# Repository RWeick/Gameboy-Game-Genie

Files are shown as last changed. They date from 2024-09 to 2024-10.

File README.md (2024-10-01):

# Gameboy-Game-Genie
The Kicad files and rom dump of the Gameboy Game Genie by Galoob. This includes the additional PCBs for the buttons and the LED.

In the replacement board folder, you will find a version of the PCB that uses an Atmel AT27C256 (or chip of compatible size and pinout) to replace the chip blob. This enables anyone with a damaged PCB to restore the system. It has been tested.

PCB Thicknesses: 0.8 mm

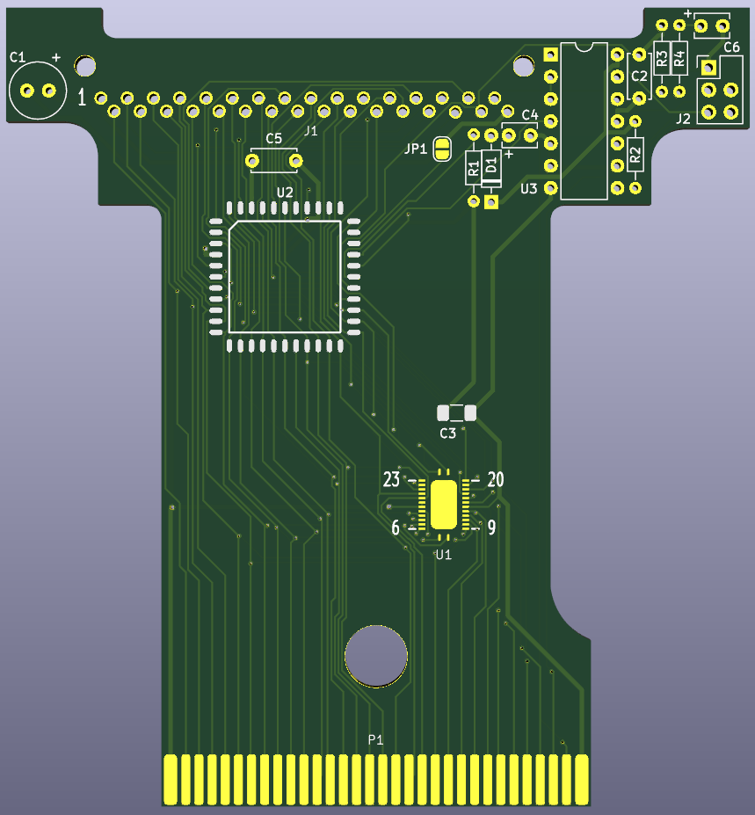
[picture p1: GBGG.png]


Replacement Board:

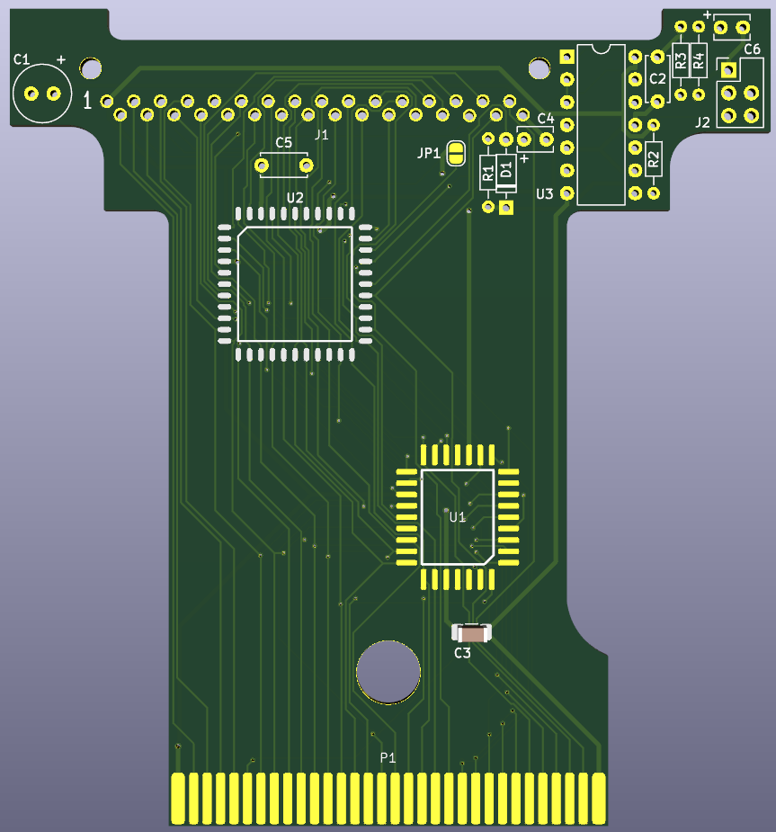
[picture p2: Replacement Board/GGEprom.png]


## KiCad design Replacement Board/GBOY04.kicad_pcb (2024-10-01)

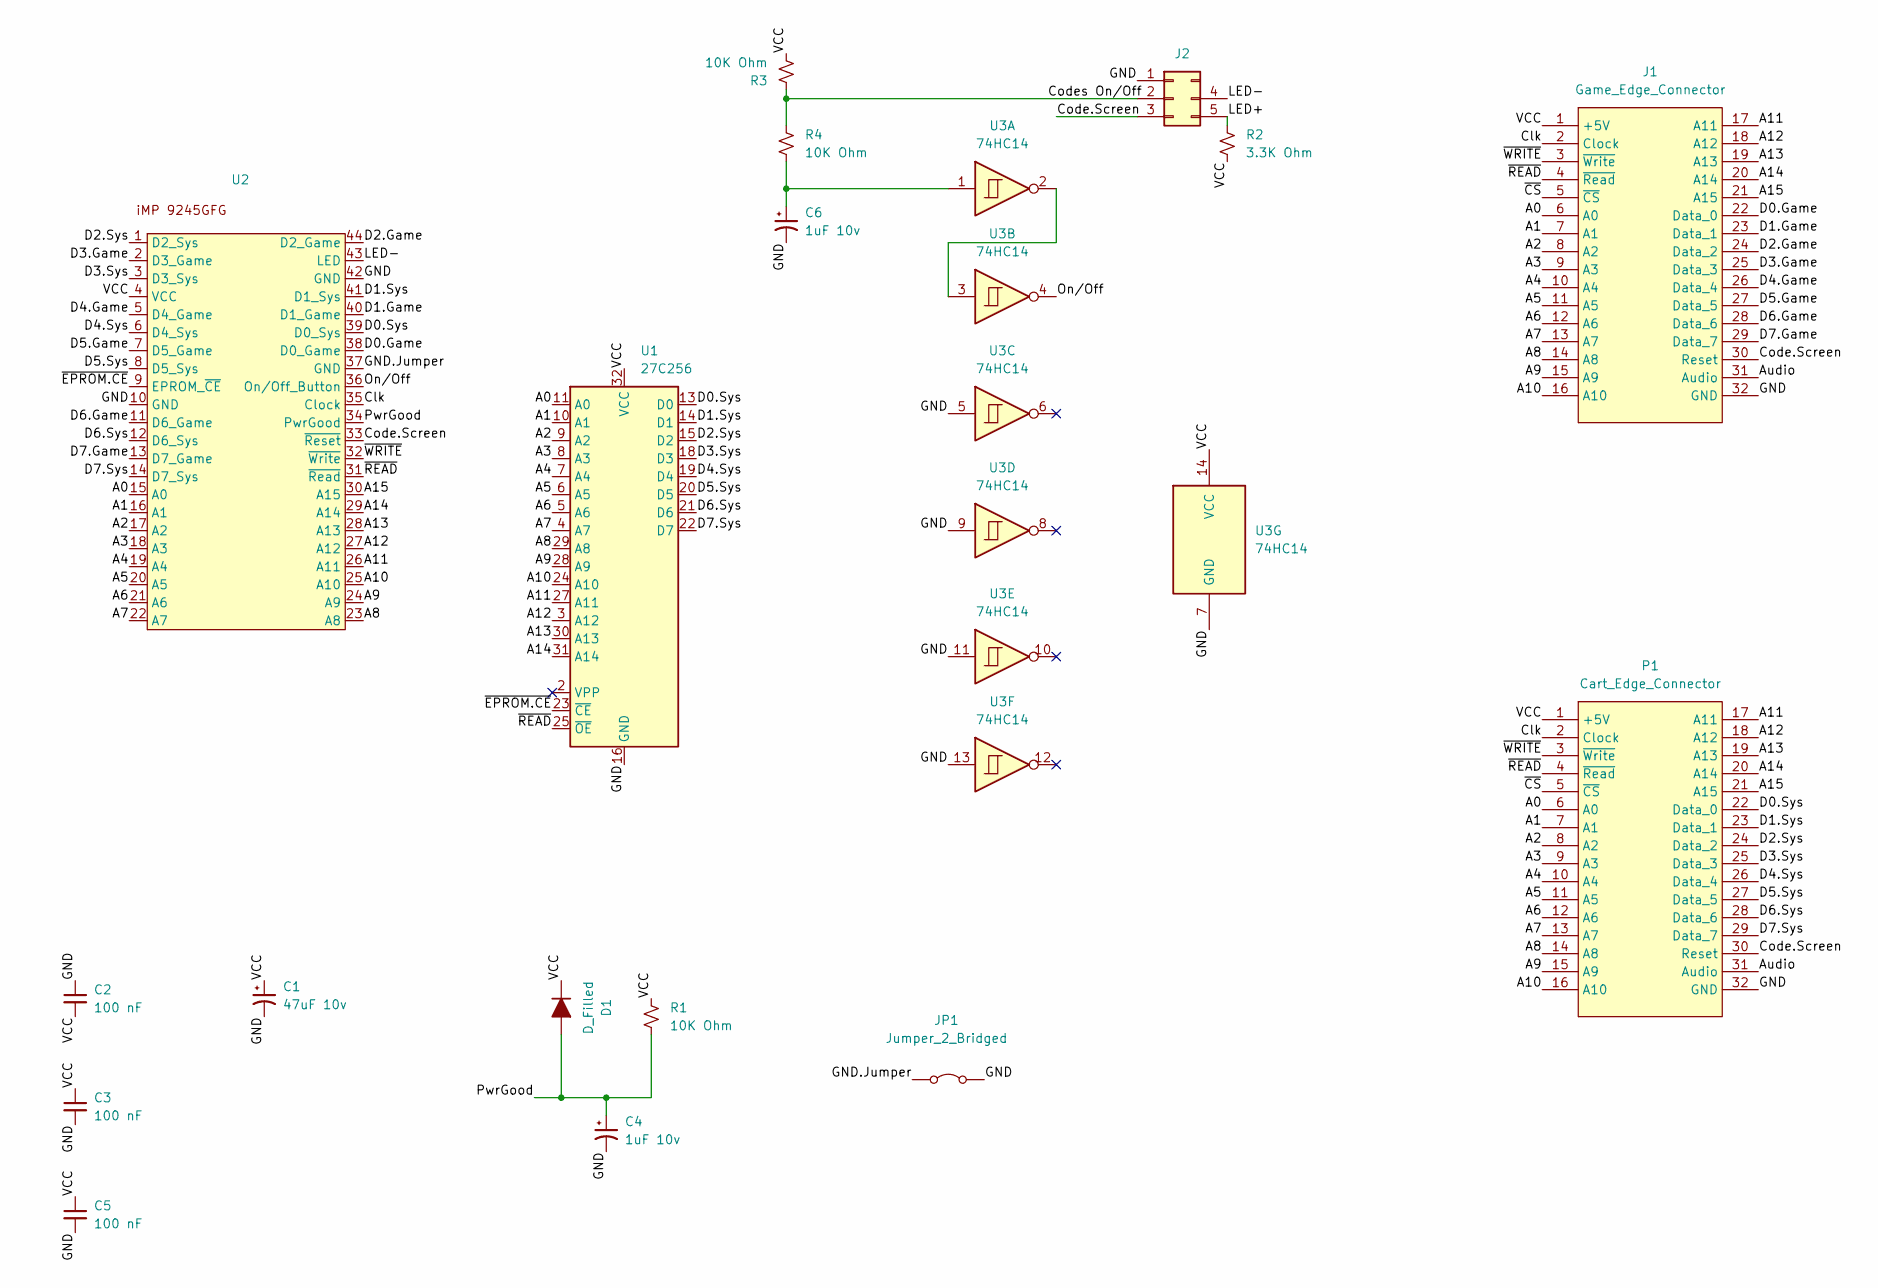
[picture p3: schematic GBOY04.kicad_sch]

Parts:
C1: 47uF 10v; C_Radial_D6.3mm_H5.0mm_P2.50mm
C2, C5: 100 nF; C_Disc_D5.0mm_W2.5mm_P5.00mm
C3: 100 nF; C_1206_3216Metric_Pad1.33x1.80mm_HandSolder
C4, C6: 1uF 10v; C_Disc_D3.8mm_W2.6mm_P2.50mm
D1: D_Filled; D_DO-35_SOD27_P7.62mm_Horizontal
J1: Game_Edge_Connector; Cartridge Connector
J2: Conn_02x03_Counter_Clockwise; PinHeader_2x03_P2.54mm_Vertical
JP1: Jumper_2_Bridged; SolderJumper-2_P1.3mm_Open_RoundedPad1.0x1.5mm
P1: Cart_Edge_Connector; Edge Connector
R1, R3, R4: 10K Ohm; R_Axial_DIN0204_L3.6mm_D1.6mm_P7.62mm_Horizontal
R2: 3.3K Ohm; R_Axial_DIN0204_L3.6mm_D1.6mm_P7.62mm_Horizontal
U1: 27C256; EPROM
U2: iMP PLD
U3: 74HC14; DIP-14_W7.62mm

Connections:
/A0: J1.6 (A0), P1.6 (A0), U1.11 (A0), U2.15 (A0)
/A1: J1.7 (A1), P1.7 (A1), U1.10 (A1), U2.16 (A1)
/A2: J1.8 (A2), P1.8 (A2), U1.9 (A2), U2.17 (A2)
/A3: J1.9 (A3), P1.9 (A3), U1.8 (A3), U2.18 (A3)
/A4: J1.10 (A4), P1.10 (A4), U1.7 (A4), U2.19 (A4)
/A5: J1.11 (A5), P1.11 (A5), U1.6 (A5), U2.20 (A5)
/A6: J1.12 (A6), P1.12 (A6), U1.5 (A6), U2.21 (A6)
/A7: J1.13 (A7), P1.13 (A7), U1.4 (A7), U2.22 (A7)
/A8: J1.14 (A8), P1.14 (A8), U1.29 (A8), U2.23 (A8)
/A9: J1.15 (A9), P1.15 (A9), U1.28 (A9), U2.24 (A9)
/A10: J1.16 (A10), P1.16 (A10), U1.24 (A10), U2.25 (A10)
/A11: J1.17 (A11), P1.17 (A11), U1.27 (A11), U2.26 (A11)
/A12: J1.18 (A12), P1.18 (A12), U1.3 (A12), U2.27 (A12)
/A13: J1.19 (A13), P1.19 (A13), U1.30 (A13), U2.28 (A13)
/A14: J1.20 (A14), P1.20 (A14), U1.31 (A14), U2.29 (A14)
/A15: J1.21 (A15), P1.21 (A15), U2.30 (A15)
/Audio: J1.31 (Audio), P1.31 (Audio)
/Clk: J1.2 (Clock), P1.2 (Clock), U2.35 (Clock)
/Code.Screen: J1.30 (Reset), J2.3, P1.30 (Reset), U2.33 (~Reset)
/Codes On/Off: J2.2, R3.1, R4.1
/D0.Game: J1.22 (Data_0), U2.38 (D0_Game)
/D0.Sys: P1.22 (Data_0), U1.13 (D0), U2.39 (D0_Sys)
/D1.Game: J1.23 (Data_1), U2.40 (D1_Game)
/D1.Sys: P1.23 (Data_1), U1.14 (D1), U2.41 (D1_Sys)
/D2.Game: J1.24 (Data_2), U2.44 (D2_Game)
/D2.Sys: P1.24 (Data_2), U1.15 (D2), U2.1 (D2_Sys)
/D3.Game: J1.25 (Data_3), U2.2 (D3_Game)
/D3.Sys: P1.25 (Data_3), U1.18 (D3), U2.3 (D3_Sys)
/D4.Game: J1.26 (Data_4), U2.5 (D4_Game)
/D4.Sys: P1.26 (Data_4), U1.19 (D4), U2.6 (D4_Sys)
/D5.Game: J1.27 (Data_5), U2.7 (D5_Game)
/D5.Sys: P1.27 (Data_5), U1.20 (D5), U2.8 (D5_Sys)
/D6.Game: J1.28 (Data_6), U2.11 (D6_Game)
/D6.Sys: P1.28 (Data_6), U1.21 (D6), U2.12 (D6_Sys)
/D7.Game: J1.29 (Data_7), U2.13 (D7_Game)
/D7.Sys: P1.29 (Data_7), U1.22 (D7), U2.14 (D7_Sys)
/GND: C1.2, C2.1, C3.2, C4.2, C5.2, C6.2, J1.32 (GND), J2.1, JP1.2 (B), P1.32 (GND), U1.16 (GND), U2.10 (GND), U2.42 (GND), U3.5, U3.7 (GND), U3.9, U3.11, U3.13
/GND.Jumper: JP1.1 (A), U2.37 (GND)
/LED+: J2.5, R2.1
/LED-: J2.4, U2.43 (LED)
/On/Off: U2.36 (On/Off_Button), U3.4
/PwrGood: C4.1, D1.2 (A), R1.2, U2.34 (PwrGood)
/VCC: C1.1, C2.2, C3.1, C5.1, D1.1 (K), J1.1 (+5V), P1.1 (+5V), R1.1, R2.2, R3.2, U1.32 (VCC), U2.4 (VCC), U3.14 (VCC)
/~CS: J1.5 (~CS), P1.5 (~CS)
/~EPROM.CE: U1.23 (~CE), U2.9 (EPROM_~CE)
/~READ: J1.4 (~Read), P1.4 (~Read), U1.25 (~OE), U2.31 (~Read)
/~WRITE: J1.3 (~Write), P1.3 (~Write), U2.32 (~Write)
unnamed: C6.1, R4.2, U3.1
unnamed: U3.2, U3.3

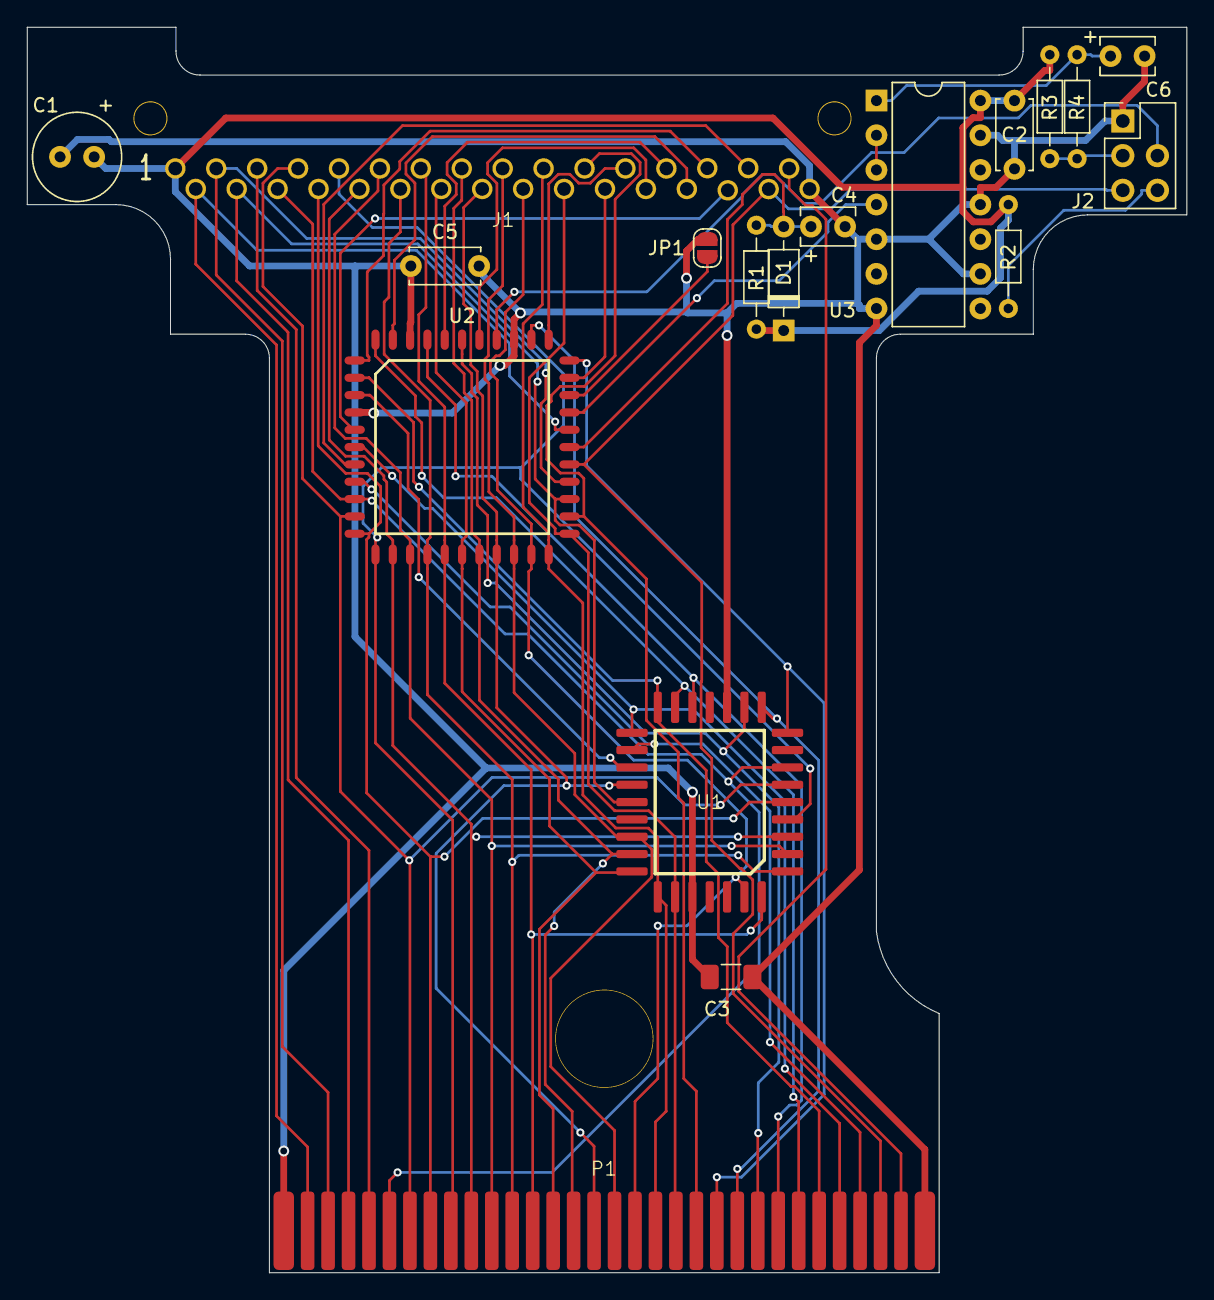
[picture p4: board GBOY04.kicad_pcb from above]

Board: 2 copper layers, 85.0 x 91.3 mm, 19 parts (0 on the bottom side), 49 nets.

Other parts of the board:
Hole: Drill Hole

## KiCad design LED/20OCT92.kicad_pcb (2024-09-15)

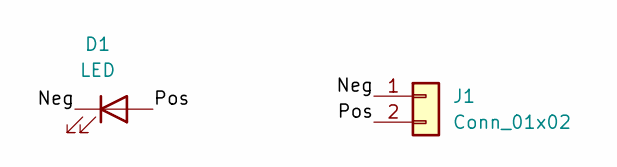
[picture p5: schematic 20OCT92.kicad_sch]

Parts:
D1: LED; LED_D4.0mm
J1: Conn_01x02; PinHeader_1x02_P2.54mm_Vertical

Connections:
/Neg: D1.1 (K), J1.1
/Pos: D1.2 (A), J1.2

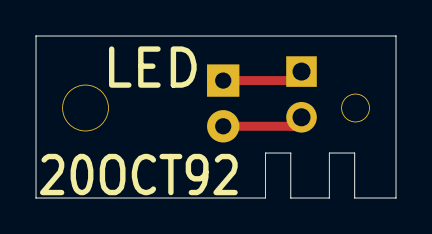
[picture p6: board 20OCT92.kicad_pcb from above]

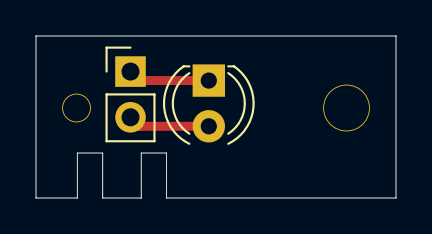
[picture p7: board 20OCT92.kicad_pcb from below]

Board: 2 copper layers, 20.0 x 9.0 mm, 3 parts (2 on the bottom side), 2 nets.

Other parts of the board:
Hole: Drill Holes

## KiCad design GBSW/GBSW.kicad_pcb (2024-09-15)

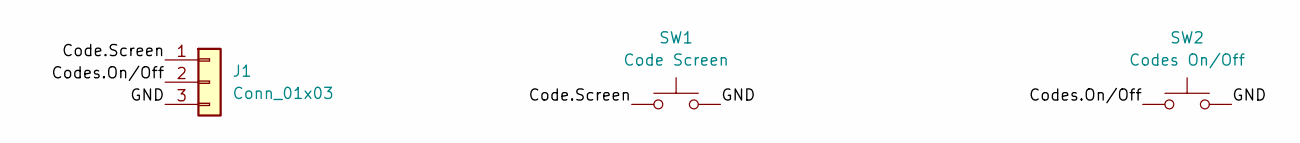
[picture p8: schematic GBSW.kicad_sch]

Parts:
J1: Conn_01x03; Wires
SW1: Code Screen; Buttons
SW2: Codes On/Off; Buttons

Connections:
/Code.Screen: J1.1, SW1.1
/Codes.On/Off: J1.2, SW2.1
/GND: J1.3, SW1.2, SW2.2

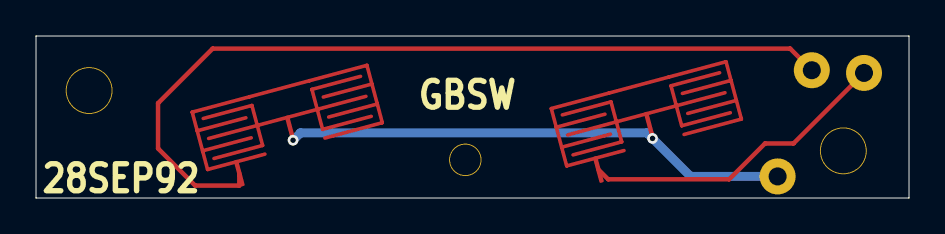
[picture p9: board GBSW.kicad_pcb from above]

Board: 2 copper layers, 48.5 x 9.0 mm, 4 parts (0 on the bottom side), 3 nets.

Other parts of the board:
Holes: Drill Holes
